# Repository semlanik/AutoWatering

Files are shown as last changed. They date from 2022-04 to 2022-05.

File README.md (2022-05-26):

**Parts are used in the project**
- [Moisture sensors](https://www.amazon.de/gp/product/B088LPJL7Q/ref=ppx_yo_dt_b_asin_title_o04_s01?ie=UTF8&psc=1)
- [Pumps](https://www.amazon.de/-/en/gp/product/B07J5CY7B8/ref=ppx_yo_dt_b_asin_title_o08_s01?ie=UTF8&psc=1)
- [Junctions](https://www.amazon.de/gp/product/B09C8CJPG7/ref=ppx_yo_dt_b_asin_title_o03_s00?ie=UTF8&psc=1)
- [LDO](https://www.reichelt.de/ldo-spannungsregler-fix-5-v-800ma-sot-223-lm-1117-mp5-0-p109330.html?&nbc=1)
- [N-Channel FETs](https://www.reichelt.de/mosfet-n-kanal-20-v-4-2-a-rds-on-0-045-ohm-sot-23-irlml-2502-p108737.html?&nbc=1)
- [Arduino](https://www.reichelt.de/arduino-nano-every-atmega4809-mit-header-ard-nano-eve-h-p261301.html?&nbc=1)
- Misc: resistors, capacitors

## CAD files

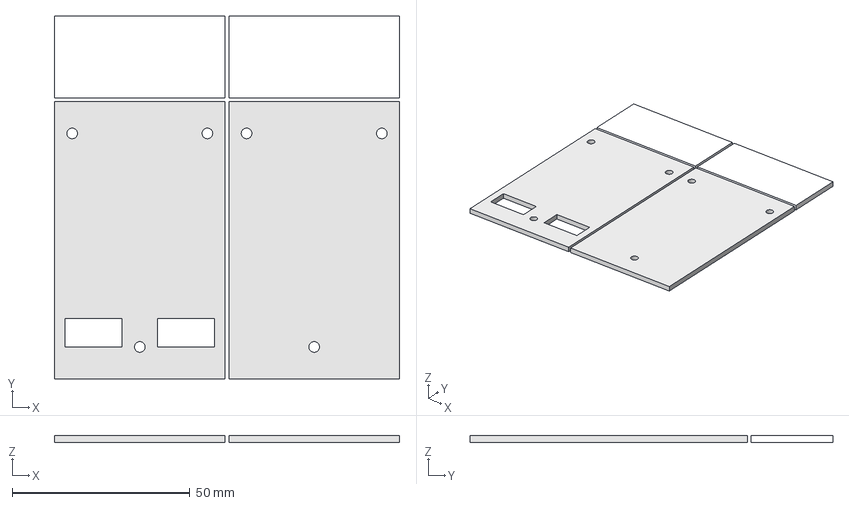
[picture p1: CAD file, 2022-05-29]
Case.FCStd
97.0 x 102.0 x 2.00 mm

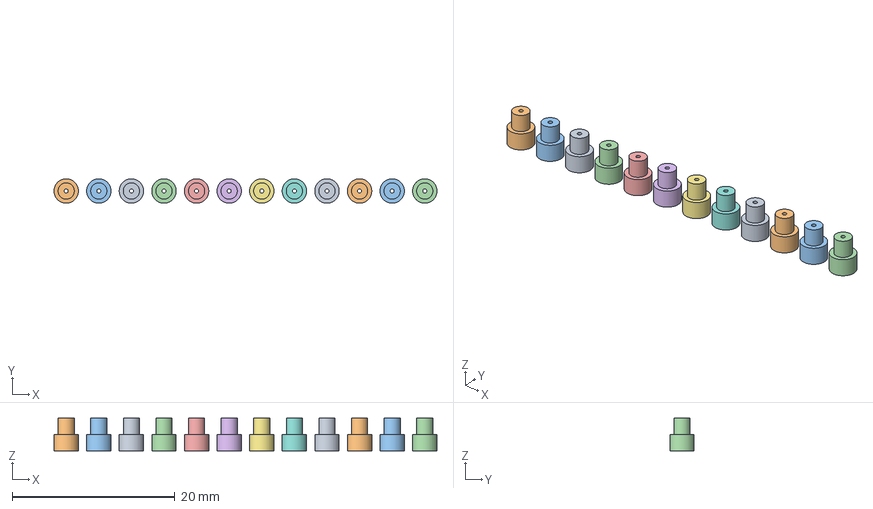
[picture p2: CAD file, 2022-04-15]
Nozzle/Nozzle.FCStd
47.0 x 3.00 x 4.00 mm

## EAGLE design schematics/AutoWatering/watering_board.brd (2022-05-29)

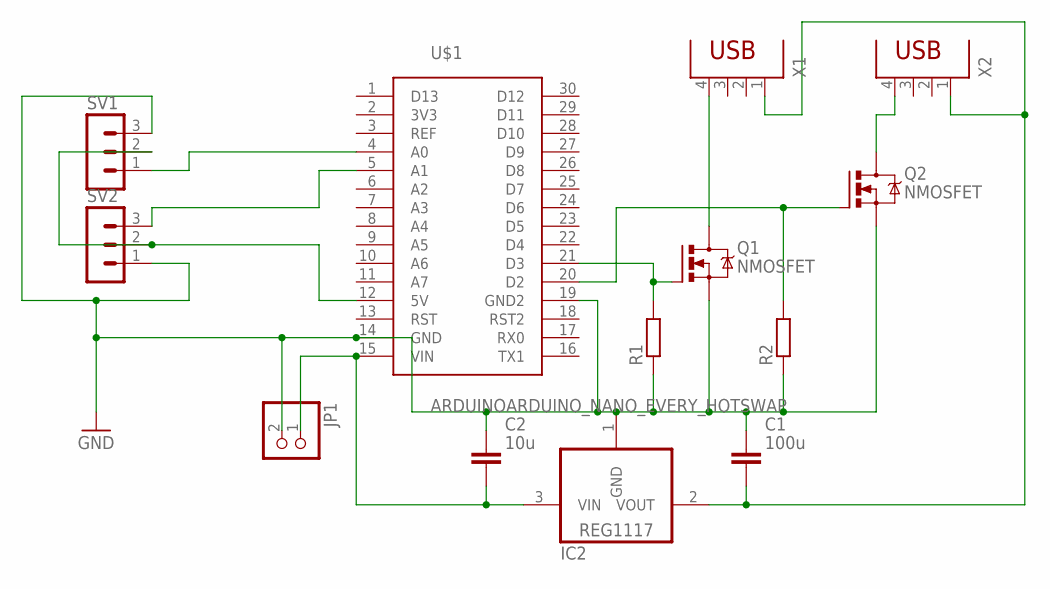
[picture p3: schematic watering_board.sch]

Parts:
C1: 100u; CAPC3216X135
C2: 10u; CAPC3216X135
IC2: REG1117; SOT223
JP1: PINHD-1X2; 1X02
Q1, Q2: NMOSFET; SOT23
R1, R2: R-EU_M1206; M1206
SV1, SV2: MA03-1
U$1: ARDUINOARDUINO_NANO_EVERY_HOTSWAP; DIP1524W80P254L4318H508Q30B
X1, X2: PN87520

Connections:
3V3: U$1.2 (3V3)
GND: C1.1, C2.1, IC2.1 (GND), JP1.2, Q1.2 (S), Q2.2 (S), R1.1, R2.1, SV1.3, SV2.1, U$1.14 (GND), U$1.19 (GND2)
unnamed: SV1.1, U$1.4 (A0)
unnamed: SV2.3, U$1.5 (A1)
unnamed: SV1.2, SV2.2, U$1.12 (5V)
unnamed: C2.2, IC2.3 (VIN), JP1.1, U$1.15 (VIN)
unnamed: Q2.1 (G), R2.2, U$1.20 (D2)
unnamed: Q1.3 (D), X1.4
unnamed: Q2.3 (D), X2.4
unnamed: Q1.1 (G), R1.2, U$1.21 (D3)
unnamed: C1.2, IC2.2 (VOUT), X1.1, X2.1

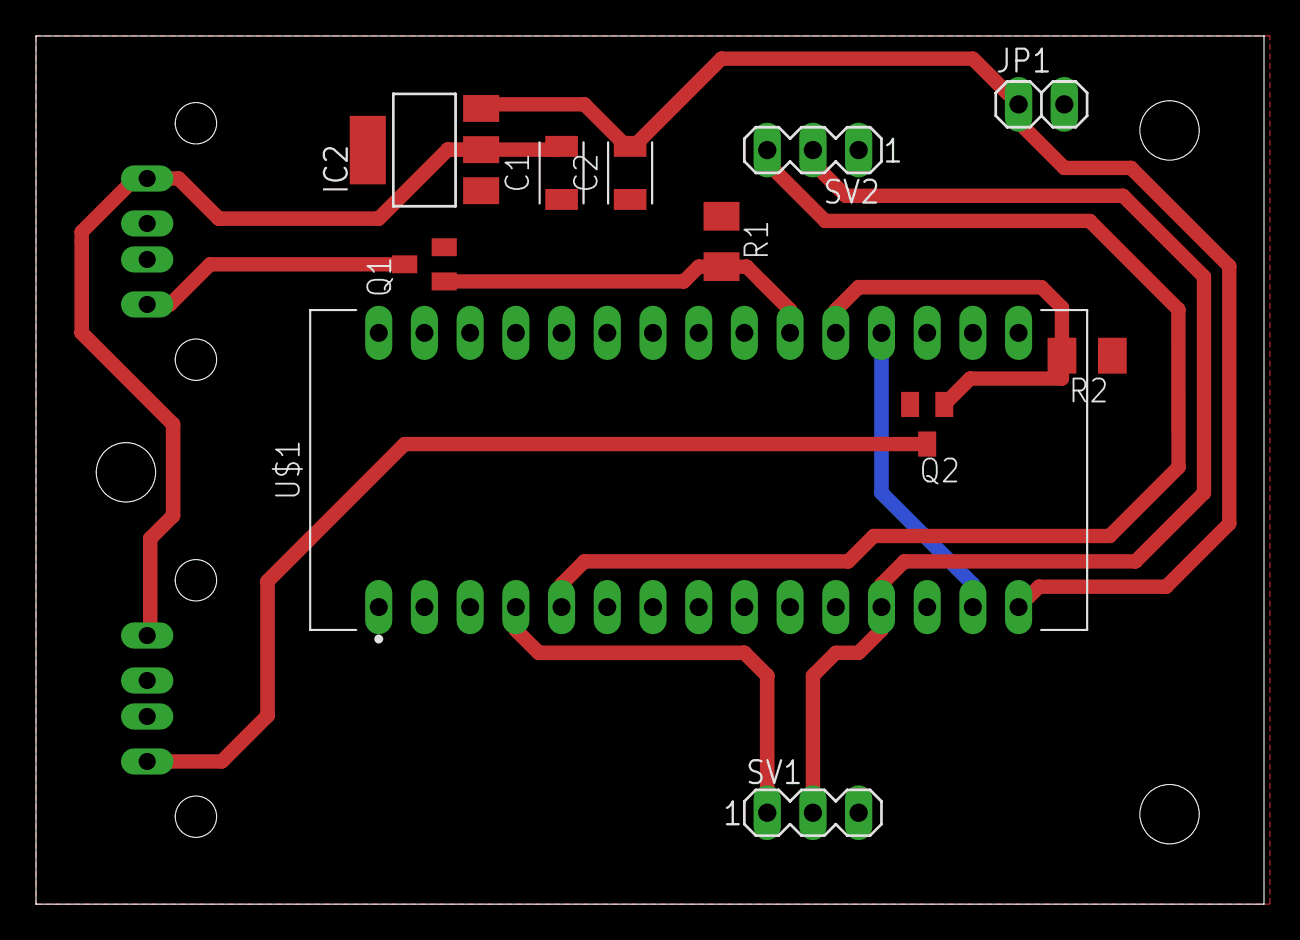
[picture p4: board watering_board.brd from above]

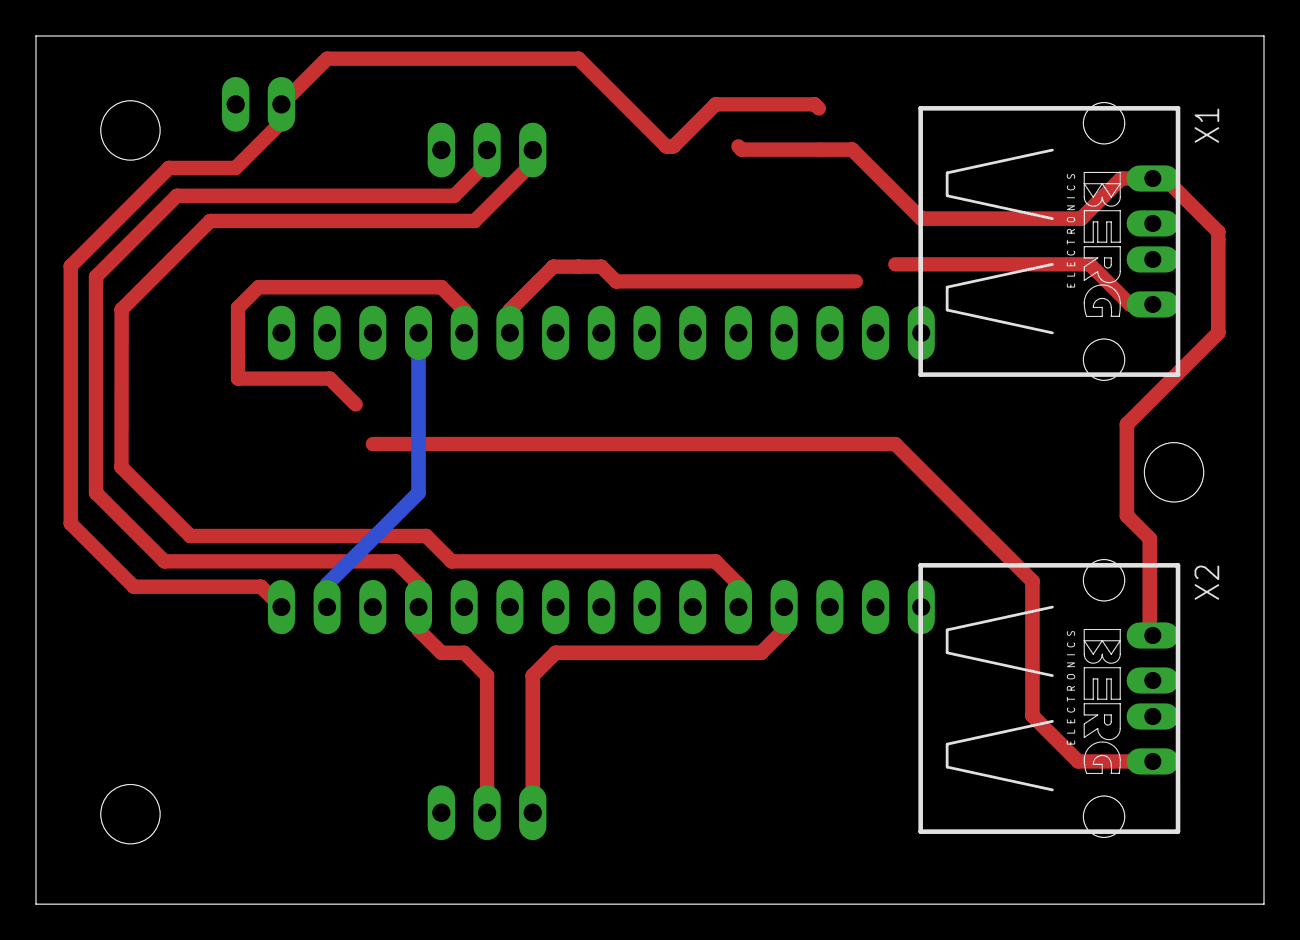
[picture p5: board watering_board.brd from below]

Board: 2 copper layers, 68.2 x 48.2 mm, 13 parts (2 on the bottom side), 10 nets.

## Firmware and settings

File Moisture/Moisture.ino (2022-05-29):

#define SerialDebug(X) Serial.print(X)
//#define SerialDebug(X)


#include <avr/sleep.h>

class WateringStateMachine
{
    enum State {
        Idle,
        Watering,
        Pause
    };
    static const short MoistureMin = 35;
    static const short MoistureMax = 55;
    static const short WateringTimeout = 2000;
    static const short PauseTimeout = 3000;
    static const short mTick = 500;

    int mSensor = 0;
    int mMotor = 0;
    short mAirValue = 0;
    short mWaterValue = 0;

    State mCurrentState = Idle;
    short mMoistureCurrent = MoistureMin;
    short mActiveTimer = 0;


    void execIdle()
    {
        if (mMoistureCurrent < MoistureMin) {
            setState(Watering);
        }
    }

    void execWatering()
    {
        if (mMoistureCurrent >= MoistureMax && mActiveTimer >= WateringTimeout) {
            setState(Idle);
            return;
        }

        if (mActiveTimer >= WateringTimeout) {
            setState(Pause);
            return;
        }
    }

    void execPause()
    {
        if (mMoistureCurrent >= MoistureMax) {
            setState(Idle);
            return;
        }

        if (mActiveTimer >= PauseTimeout) {
            setState(Watering);
            return;
        }
    }

    void setState(State state) {
        mActiveTimer = 0;
        mCurrentState = state;
    }
public:
    WateringStateMachine(int sensor, int motor, short airValue, short waterValue) :
        mSensor(sensor),
        mMotor(motor),
        mAirValue(airValue),
        mWaterValue(waterValue)
    {
    }

    void readMeanMoisture()
    {
        // Make 3 read attempt to be on a safe side. Use the lowest raw value (means highest
        // moisture).
        short raw = analogRead(mSensor);
        for(int i = 0; i < 5; i++) {
            delay(mTick/5);
            short tmp = analogRead(mSensor);
            if (tmp < raw) {
                raw = tmp;
            }
        }
        mMoistureCurrent = map(raw, mAirValue, mWaterValue, 0, 100);
        SerialDebug("    raw: ");
        SerialDebug(raw);
        SerialDebug("    moisture: ");
        SerialDebug(mMoistureCurrent);
        SerialDebug("\n");
    }

    void execute()
    {
        SerialDebug("sensor: ");
        SerialDebug(mSensor);
        readMeanMoisture();
        SerialDebug("\n");

        execIdle();
        while (mCurrentState != Idle)
        {
            SerialDebug("    state: ");
            SerialDebug(mCurrentState);
            SerialDebug("\n");

            readMeanMoisture();
            mActiveTimer += mTick;
            if (mCurrentState == Watering) {
                digitalWrite(mMotor, HIGH);
                execWatering();
            } else if (mCurrentState == Pause) {
                digitalWrite(mMotor, LOW);
                execPause();
            } else {
                break;
            }
        }

        digitalWrite(mMotor, LOW);
    }
};

static WateringStateMachine stateMachine1(A0, 2, 876, 680);
static WateringStateMachine stateMachine2(A1, 3, 945, 808);

ISR(RTC_PIT_vect)
{
    RTC.PITINTFLAGS = RTC_PI_bm;          // Clear interrupt flag by writing '1' (required) 
}

void initRTC(void)
{
    while (RTC.STATUS > 0);
    RTC.CLKSEL = RTC_CLKSEL_INT1K_gc;
    RTC.PITINTCTRL = RTC_PI_bm;
    RTC.PITCTRLA = RTC_PERIOD_CYC8192_gc | RTC_PITEN_bm;
}

void setup() {
    Serial.begin(115200);
    pinMode(2, OUTPUT);
    pinMode(3, OUTPUT);

    initRTC();
    set_sleep_mode(SLEEP_MODE_PWR_DOWN);
    sleep_enable();
}

void loop() {
//    sleep_cpu();
    // Make the run of state machines async since we may run into situation with simulatous
    // start of 2 electric motors will set the LDO into the block and arduino will be out of power.
    // Current schematic supports only 0.8A current for motors. Need to improve it to support higher
    // current.
    delay(1000); // Give sensor the chance to wake up and provide better values.
    stateMachine1.execute();
    delay(500);
    stateMachine2.execute();
    delay(500);
}

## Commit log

2022-04-08 Add missing LSO capacitors
    [watering_board.brd, watering_board.sch]
2022-04-10 Recalibrate sensors
2022-04-15 Add powersafe mode
    Add powersafe mode for arduino with watch dog wake up mechanism.
    Add nozzle 3d model and grbl file.
    [Nozzle.FCStd]
2022-05-02 Add an extra deplay after sleep before reading sensors
2022-05-26 Use USB A conntector for the pump
    [watering_board.brd, watering_board.sch]
2022-05-26 Update the pump model
2022-05-29 Add the case
    Add the case for the schematics.
    Update to Arduino every. Use the difference sleep/wakeup mechnism.
    Adjust moisture sensors.
    Update schematics to match the case.
    [Case.FCStd, watering_board.brd, watering_board.sch]
